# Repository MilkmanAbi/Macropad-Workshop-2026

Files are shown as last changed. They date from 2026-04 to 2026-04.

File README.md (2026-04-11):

# SPIC Macropad Workshop 2026

<div align="center">

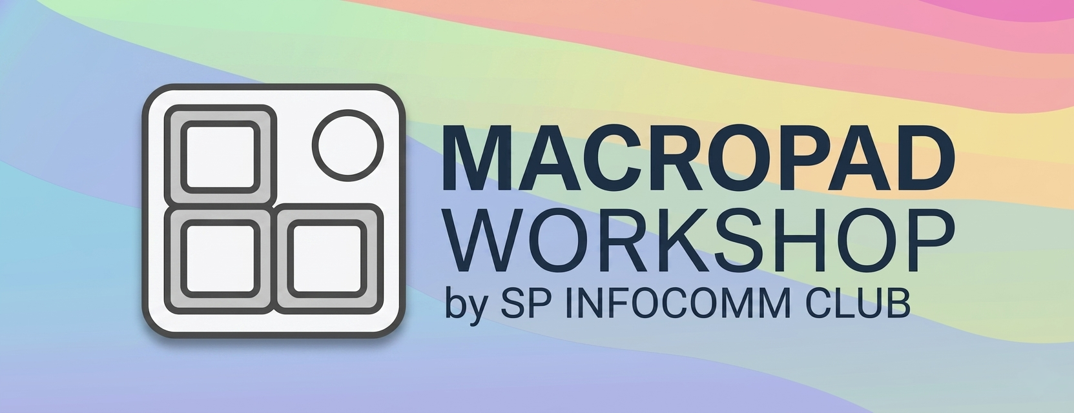
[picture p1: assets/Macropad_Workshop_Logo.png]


</div>

---

## “Yay! You made a custom keyboard… 😄”

“…Eh. A tiny one.”

**A MACROPAD!!! 😆✨**

SPIC Macropad Workshop 2026 💖

---

## What is this???

A macropad is a small programmable keyboard.

This one has **3 buttons**.

That sounds too small to matter…

…but it absolutely does.

You can turn it into:
- a productivity boost 😄  
- a media controller  
- a coding shortcut machine  
- or something completely unnecessary (but satisfying) 😆✨  

Basically: small device, big personality.

(￣ー￣)

---

## Why does this exist?

Because full keyboard firmware systems feel like too much pain for something this small.

So we don’t do that.

Instead:

- Plug it in  
- Edit a simple file  
- It works instantly  

No compiling. No waiting. No “why dis broken again” moments.

Just simple control. 💖

---

## What you’ll use

- CircuitPython  
- A RP2040 board  
- 3 buttons  
- 1 RGB LED that reflects your mode... or mood 😄✨  

That’s it.

And somehow, that’s enough.

(｡•̀ᴗ-)✧

---

## What it does

Each button can do different things depending on the mode.

For example:
- Copy / Paste / Cut  
- Volume control / media playback  
- Save / Undo / Redo  
- Zoom / Teams / Discord shortcuts  
- Or your own custom chaos 😆  

Same buttons. Different behaviour. New personality.

---

## Modes

The LED tells you what mode you are in.

And each mode changes what the 3 buttons do.

You’ll find:
- Clipboard mode 😄  
- Media mode  
- Coding mode 💖  
- Communication mode (Zoom / Teams / Discord)  
- Custom mode ✨  
- A “why did I do this” mode 😆  

(you’ll understand when you see it)

---

## Switching modes

Press Button 1 + Button 2 together.

The LED changes.

That’s it.

You are now in a different mode.

(￣▽￣)

---

## Custom mode

There is a simple config file where you can define your own setup.

You choose:
- what each button does  
- what color the LED shows  
- whether it behaves normally or becomes slightly unhinged (you'll see...) 😆✨  

No complicated setup. Just edit and save.

---

## Philosophy

This is not about building a complex system.

It’s about making something small feel useful and fun.

Fast to change. Easy to understand. Immediate feedback.

If it feels complicated, it is wrong. 💖

---

## SPIC Macropad Workshop 2026

You came in thinking:

“it’s just 3 buttons…”

You leave thinking:

“Small... But big in personality... Eh.” 😄✨

---

Credits to Organisers of 2025 Macropad Workshop and Jerick Seng

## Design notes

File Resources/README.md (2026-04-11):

# Macropad Workshop
These are the files to be used in conjunction with the macropad workshop. all software files can be found under /firmware and all hardware design files can be found under hardware

This is a 3 key macropad powered either by *QMK+VIAL* or *CIRCUITPYTHON*.

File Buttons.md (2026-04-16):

## Button Layout

</div>

**Layer 0 — Clipboard** `LED: Cyan`
| BTN1 | BTN2 | BTN3 |
|---|---|---|
| Copy | Paste | Cut |

**Layer 1 — Media** `LED: Purple`
| BTN1 | BTN2 | BTN3 |
|---|---|---|
| Vol Up | Vol Down | Play/Pause |

**Layer 2 — Communication** `LED: Orange`
| BTN1 | BTN2 | BTN3 |
|---|---|---|
| Mic Toggle | Speaker Mute | Cam Toggle |

> Long press BTN1+BTN2 on this layer to cycle platform: **Teams → Zoom → Discord** (LED blinks 2/3/4 times to confirm)

**Layer 3 — Coding** `LED: Red`
| BTN1 | BTN2 | BTN3 |
|---|---|---|
| Save | Undo | Redo |

**Layer 4 — Roll** `LED: Rainbow`
| BTN1 | BTN2 | BTN3 |
|---|---|---|
| Open Browser | Secret | Secret |

**Layer 5 — Custom** `LED: Mint (default)`
> Configured via `custom.conf` — no Python needed. See file for options.

**Layer switching:** Short press BTN1+BTN2 together → next layer

---

<div align="center">

## 🎮 Secret Game Mode

</div>

Press **all three buttons at once** to trigger a hidden Simon Says memory game.

- **BTN1 = Red · BTN2 = Green · BTN3 = Blue**
- Watch the LED flash a sequence, then repeat it in order
- 3 rounds of increasing length
- Pass all 3 rounds to claim your prize 👀

---

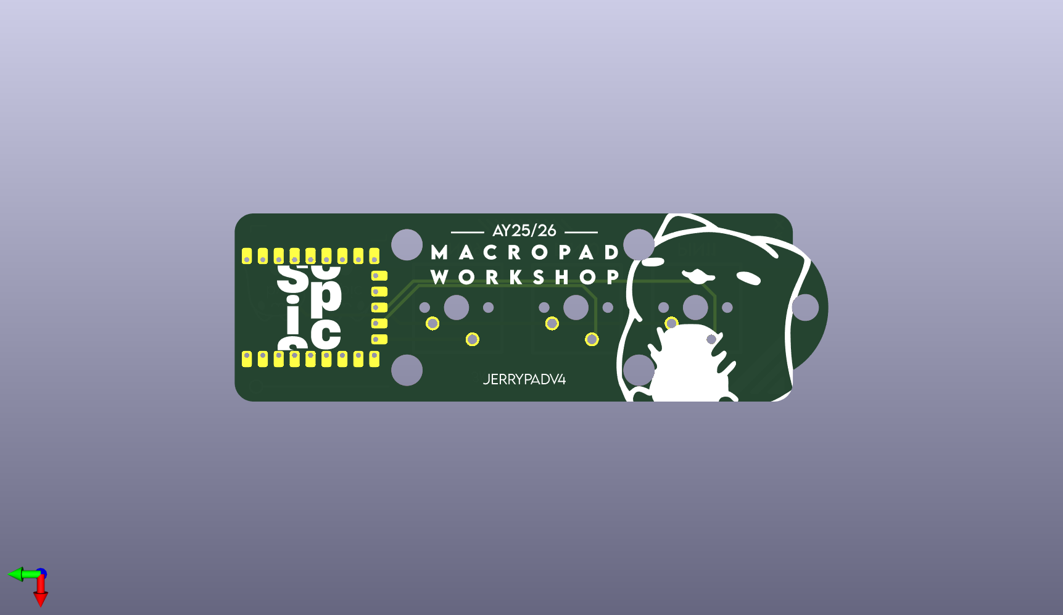
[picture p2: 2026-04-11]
Resources/Hardware-Design/V2/pcb/bottom.png

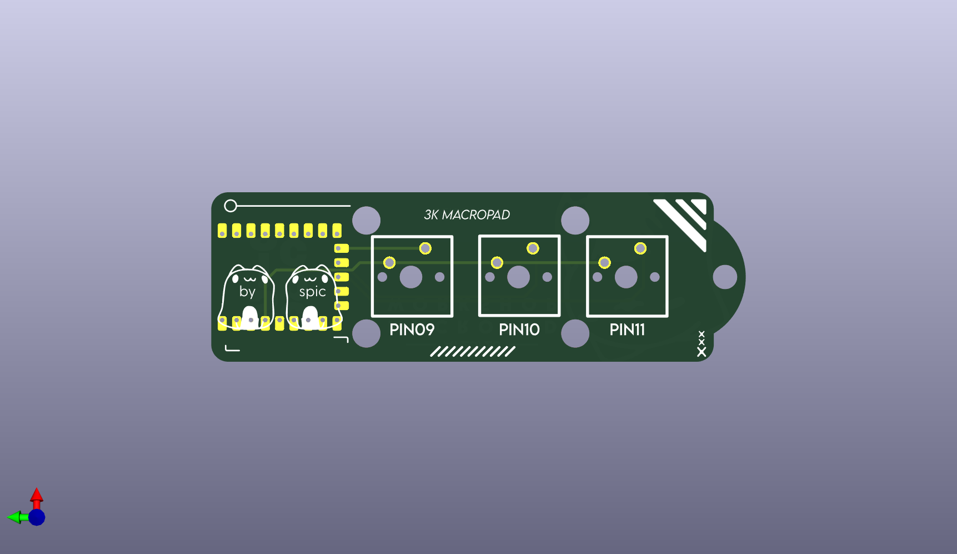
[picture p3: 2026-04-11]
Resources/Hardware-Design/V2/pcb/top.png

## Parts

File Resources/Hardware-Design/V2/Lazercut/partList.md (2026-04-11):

# Number to cut
Top.dxf x 1
Top mid.dxf x 1
Bottom Mid.dxf x 2
Base.dxf x1

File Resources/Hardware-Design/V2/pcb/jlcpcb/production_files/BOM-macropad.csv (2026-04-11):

Comment | Designator | Footprint | LCSC | Quantity
SW_SPST | SW1 | SW_Cherry_MX_1.00u_PCB |  | 1
SW_SPST | SW2 | SW_Cherry_MX_1.00u_PCB |  | 1
SW_SPST | SW3 | SW_Cherry_MX_1.00u_PCB |  | 1
RP2040-Zero | RZ1 | RP2040-Zero |  | 1

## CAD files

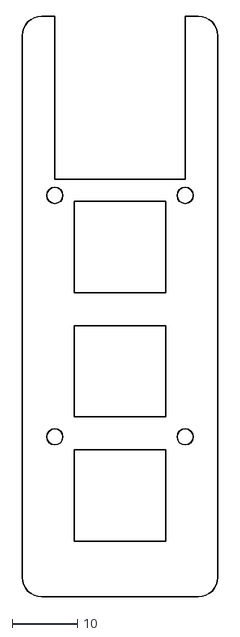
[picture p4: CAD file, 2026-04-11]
Resources/Hardware-Design/V2/Lazercut/Top.dxf
30.0 x 89.0

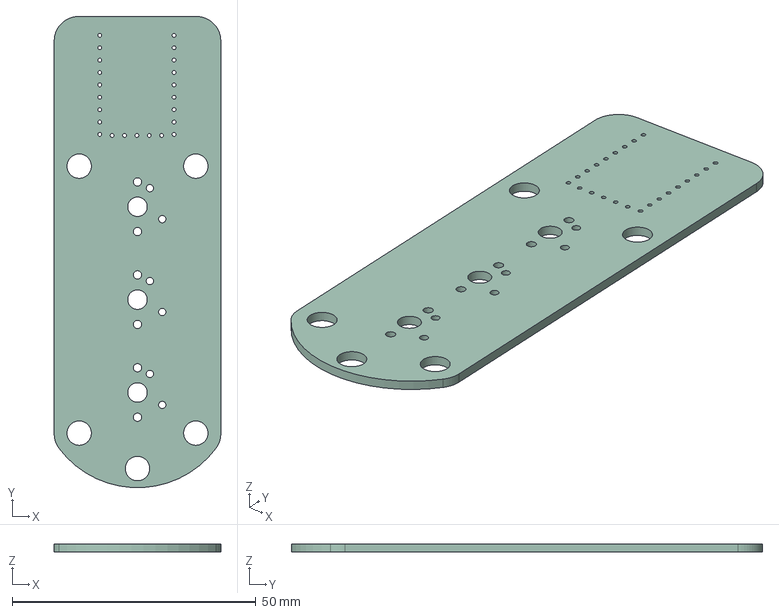
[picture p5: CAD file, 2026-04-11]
Resources/Hardware-Design/V2/pcb/macropad.step
34.2 x 96.6 x 1.60 mm

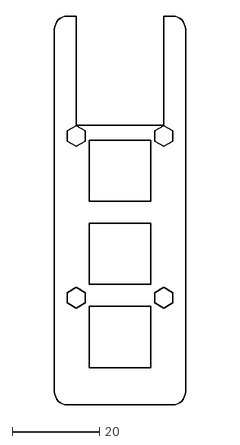
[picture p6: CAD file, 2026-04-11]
Resources/Hardware-Design/V2/Lazercut/Top mid.dxf
30.0 x 89.0

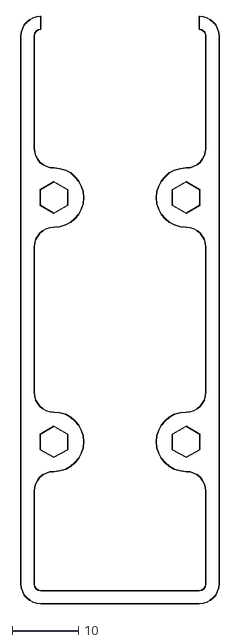
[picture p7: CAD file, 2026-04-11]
Resources/Hardware-Design/V2/Lazercut/Bottom Mid.dxf
30.0 x 89.0

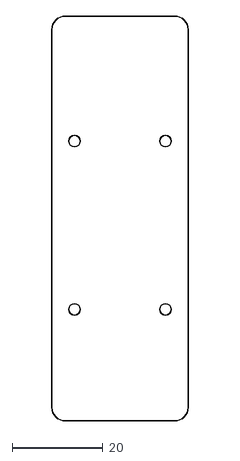
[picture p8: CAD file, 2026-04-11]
Resources/Hardware-Design/V2/Lazercut/Base.dxf
30.0 x 89.0

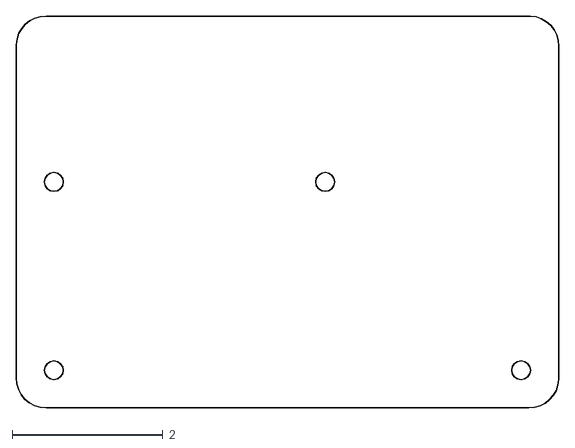
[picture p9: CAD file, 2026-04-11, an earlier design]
Resources/Hardware-Design/V1/lazercut/bottom_plate.dxf
7.20 x 5.20

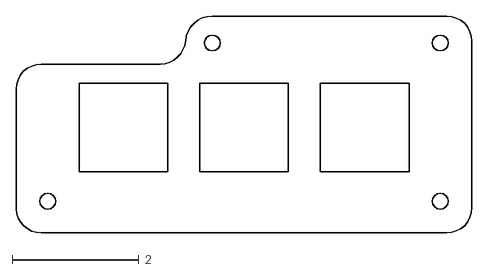
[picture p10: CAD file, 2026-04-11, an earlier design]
Resources/Hardware-Design/V1/lazercut/top_plate.dxf
7.20 x 3.43

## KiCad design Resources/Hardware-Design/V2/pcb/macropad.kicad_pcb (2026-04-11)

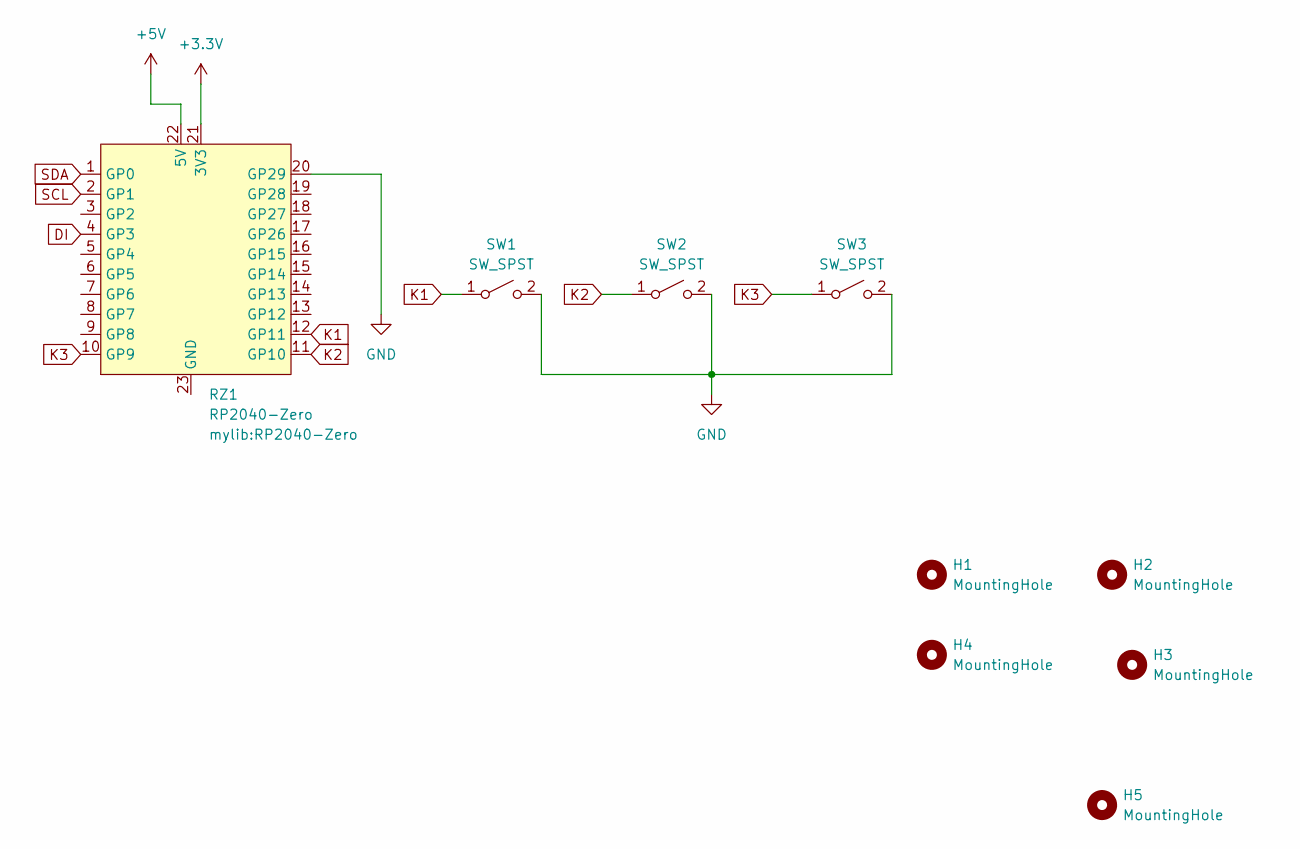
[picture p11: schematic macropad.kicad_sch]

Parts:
H1, H2, H3, H4, H5: MountingHole; MountingHole_5mm
RZ1: RP2040-Zero
SW1, SW2, SW3: SW_SPST; SW_Cherry_MX_1.00u_PCB

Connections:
+3.3V: RZ1.21 (3V3)
+5V: RZ1.22 (5V)
DI: RZ1.4 (GP3)
GND: RZ1.20 (GP29), SW1.2 (B), SW2.2 (B), SW3.2 (B)
K1: RZ1.12 (GP11), SW1.1 (A)
K2: RZ1.11 (GP10), SW2.1 (A)
K3: RZ1.10 (GP9), SW3.1 (A)
SCL: RZ1.2 (GP1)
SDA: RZ1.1 (GP0)

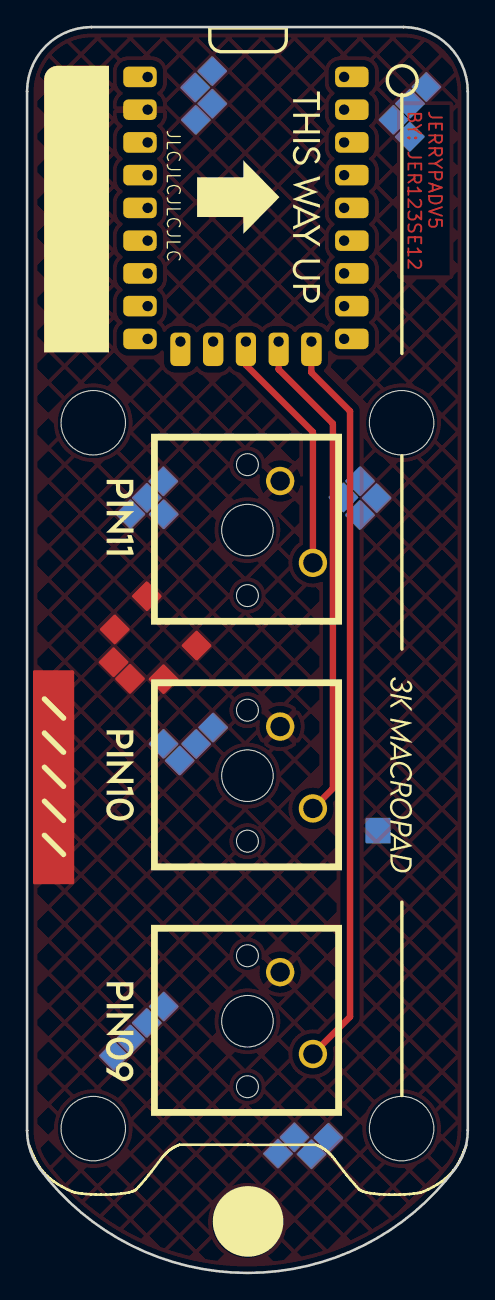
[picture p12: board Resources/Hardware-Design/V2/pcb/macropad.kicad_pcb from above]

Board: 2 copper layers, 34.2 x 96.7 mm, 9 parts (0 on the bottom side), 4 nets.

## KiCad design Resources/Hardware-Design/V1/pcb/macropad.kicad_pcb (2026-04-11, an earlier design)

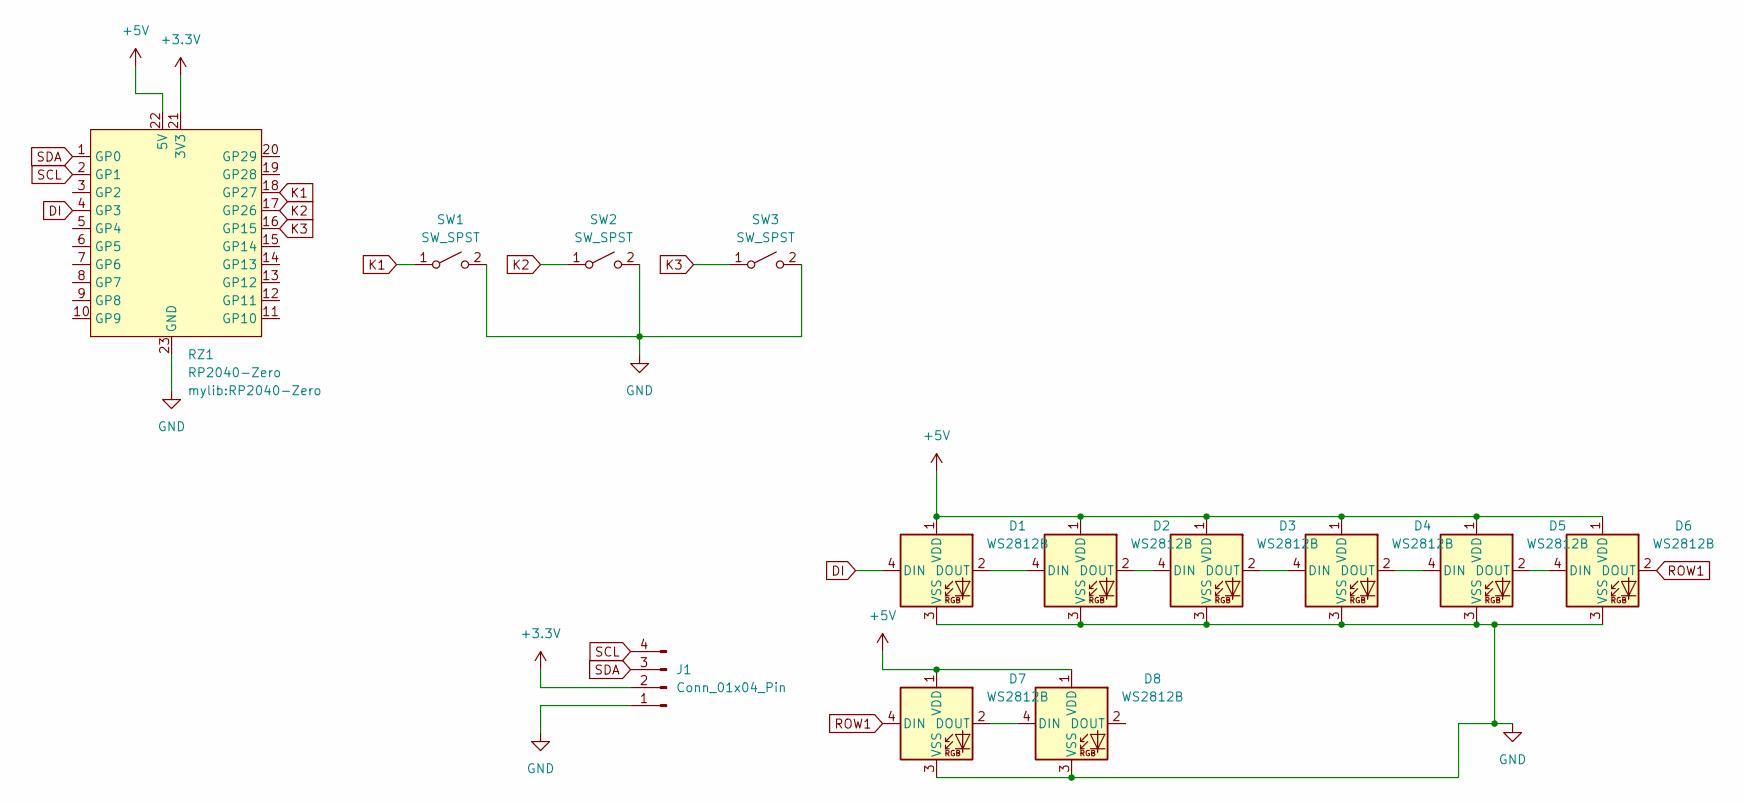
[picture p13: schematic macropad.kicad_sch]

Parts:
D1, D2, D3, D4, D5, D6, D7, D8: WS2812B; new led
J1: Conn_01x04_Pin; FanPinHeader_1x04_P2.54mm_Vertical
RZ1: RP2040-Zero
SW1, SW2, SW3: SW_SPST; SW_Cherry_MX_1.00u_PCB

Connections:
+3.3V: J1.2, RZ1.21 (3V3)
+5V: D1.1 (VDD), D2.1 (VDD), D3.1 (VDD), D4.1 (VDD), D5.1 (VDD), D6.1 (VDD), D7.1 (VDD), D8.1 (VDD), RZ1.22 (5V)
DI: D1.4 (DIN), RZ1.4 (GP3)
GND: D1.3 (VSS), D2.3 (VSS), D3.3 (VSS), D4.3 (VSS), D5.3 (VSS), D6.3 (VSS), D7.3 (VSS), D8.3 (VSS), J1.1, RZ1.23 (GND), SW1.2 (B), SW2.2 (B), SW3.2 (B)
K1: RZ1.18 (GP27), SW1.1 (A)
K2: RZ1.17 (GP26), SW2.1 (A)
K3: RZ1.16 (GP15), SW3.1 (A)
unnamed: D1.2 (DOUT), D2.4 (DIN)
unnamed: D2.2 (DOUT), D3.4 (DIN)
unnamed: D3.2 (DOUT), D4.4 (DIN)
unnamed: D4.2 (DOUT), D5.4 (DIN)
unnamed: D5.2 (DOUT), D6.4 (DIN)
unnamed: D7.2 (DOUT), D8.4 (DIN)
ROW1: D6.2 (DOUT), D7.4 (DIN)
SCL: J1.4, RZ1.2 (GP1)
SDA: J1.3, RZ1.1 (GP0)

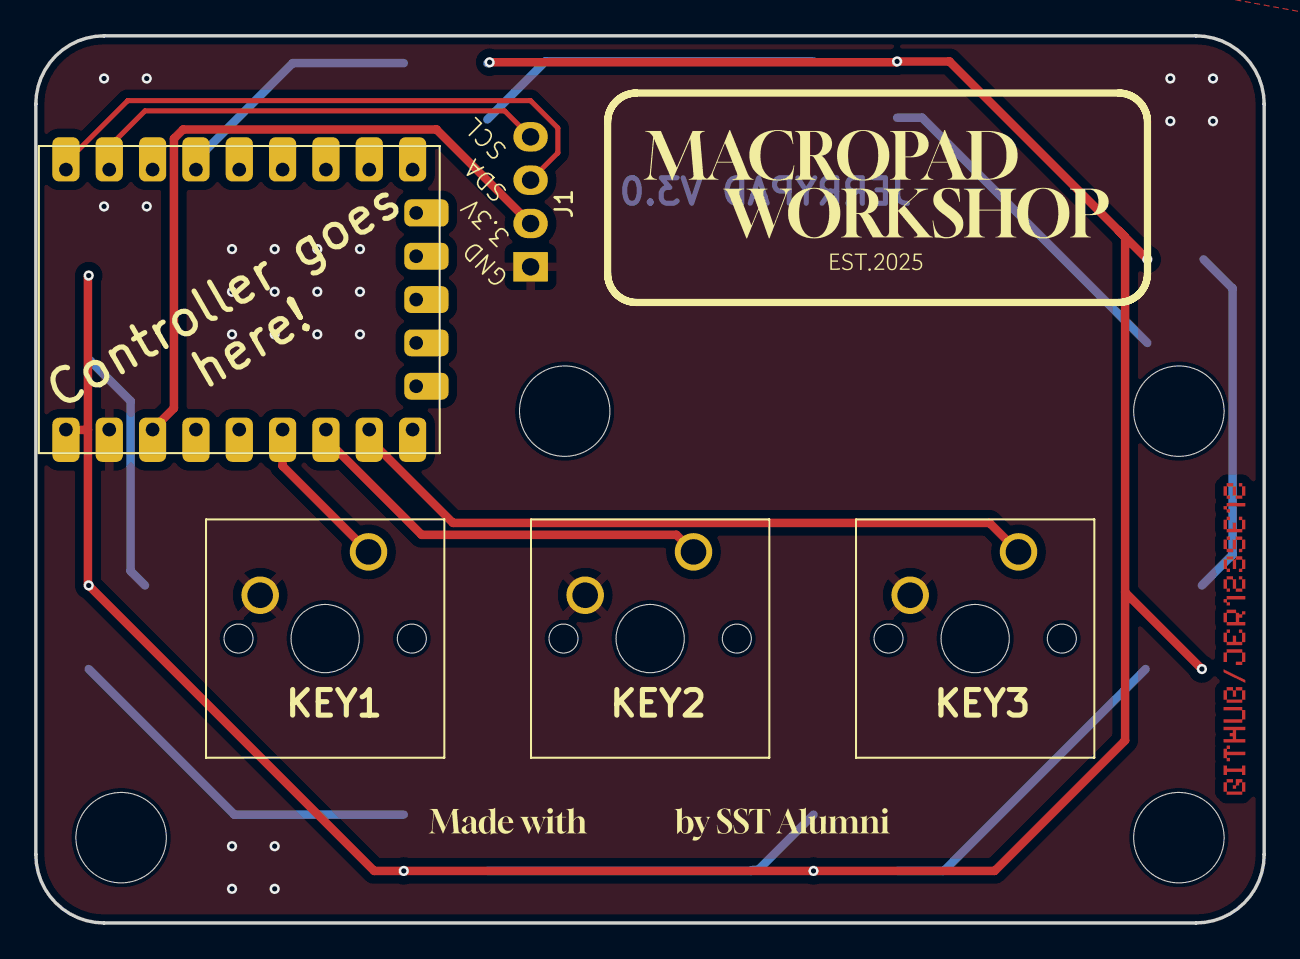
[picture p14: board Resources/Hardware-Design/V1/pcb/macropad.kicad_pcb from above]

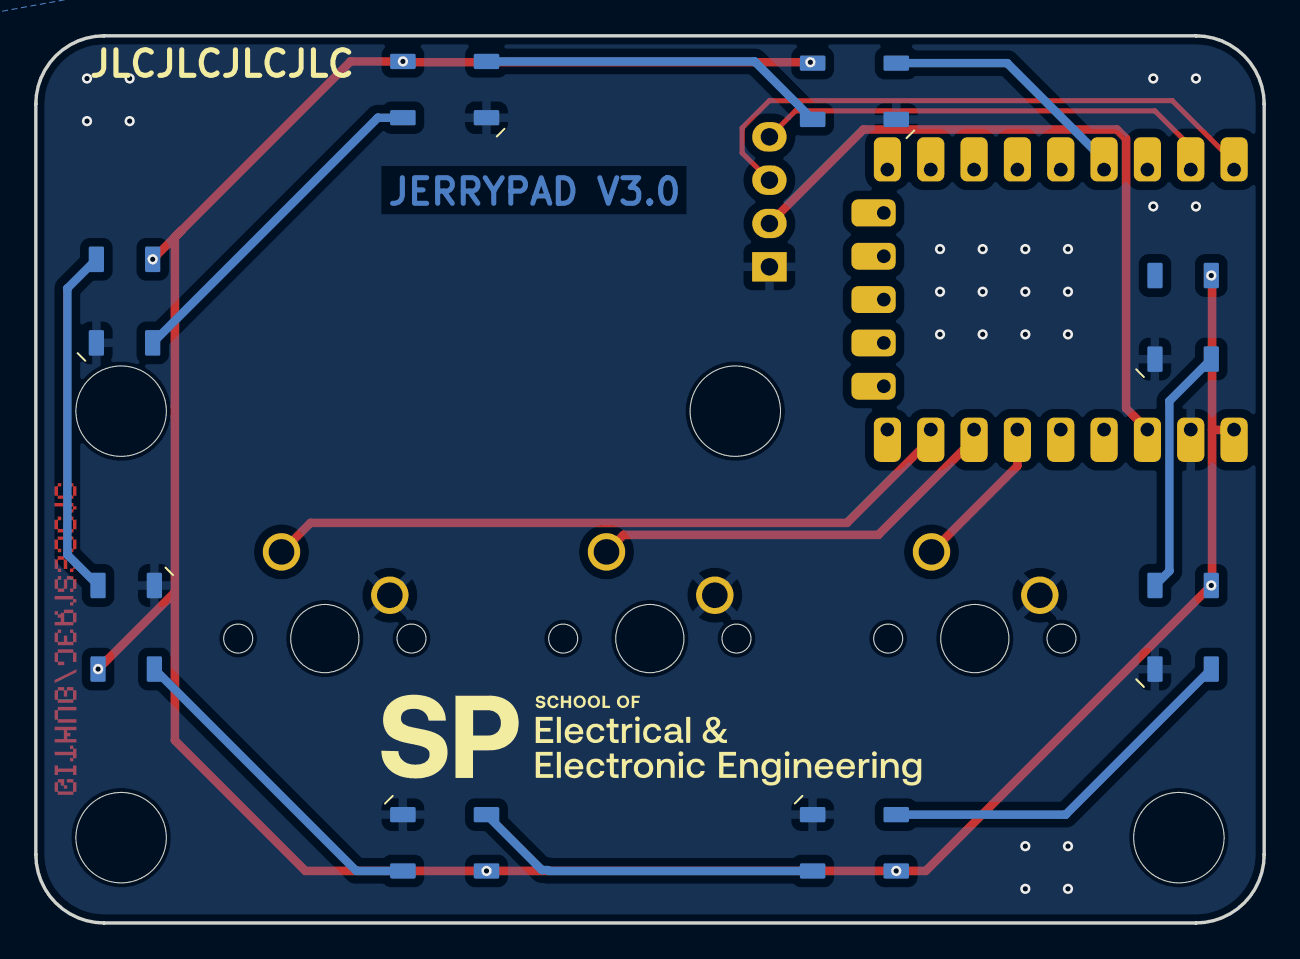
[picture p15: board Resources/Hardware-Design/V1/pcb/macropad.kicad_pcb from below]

Board: 2 copper layers, 72.0 x 52.0 mm, 13 parts (8 on the bottom side), 16 nets.

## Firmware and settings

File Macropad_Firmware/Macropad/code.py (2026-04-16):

"""
code.py — Macropad Workshop 2026
Main runtime: GPIO, mode switching, LED, execution routing.
Edit freely. No compiling. No tools. Just save and run.

Button 1 = GP9 | Button 2 = GP10 | Button 3 = GP11 | LED = GP16
"""

import board
import digitalio
import neopixel
import time
from keymaps import LAYERS, execute_action, build_custom_layer

# ── GP29 virtual GND — pull low FIRST before anything else ───────────────────
# The PCB routes switch GND through GP29 instead of actual GND.
# Must be driven low immediately or buttons are floating and won't work.
_gnd = digitalio.DigitalInOut(board.GP29)
_gnd.direction = digitalio.Direction.OUTPUT
_gnd.value = False

# ── Hardware ──────────────────────────────────────────────────────────────────

BTN_PINS = [board.GP9, board.GP10, board.GP11]
LED_PIN  = board.GP16

buttons = []
for pin in BTN_PINS:
    b = digitalio.DigitalInOut(pin)
    b.direction = digitalio.Direction.INPUT
    b.pull = digitalio.Pull.UP      # Pull-up: LOW = pressed, HIGH = not pressed
    buttons.append(b)

# pixel_order=neopixel.GRB is the WS2812B standard — stated explicitly for clarity
led = neopixel.NeoPixel(LED_PIN, 1, brightness=0.3, auto_write=True,
                        pixel_order=neopixel.GRB)

# ── Load custom.conf ──────────────────────────────────────────────────────────

def load_custom_conf():
    conf = {}
    try:
        with open("custom.conf", "r") as f:
            for line in f:
                line = line.strip()
                if not line or line.startswith("#"):
                    continue
                if "=" in line:
                    key, _, val = line.partition("=")
                    conf[key.strip().upper()] = val.strip()
    except OSError:
        pass
    return conf

LAYERS.append(build_custom_layer(load_custom_conf()))

# ── LED helpers ───────────────────────────────────────────────────────────────

RAINBOW_COLORS = [
    (255, 0,   0),
    (255, 127, 0),
    (255, 255, 0),
    (0,   255, 0),
    (0,   0,   255),
    (75,  0,   130),
    (148, 0,   211),
]
_rainbow_idx  = 0
_last_rainbow = 0.0

def set_led(color):
    if color != "RAINBOW":
        led[0] = color

def update_rainbow():
    global _rainbow_idx, _last_rainbow
    now = time.monotonic()
    if now - _last_rainbow >= 0.15:
        led[0] = RAINBOW_COLORS[_rainbow_idx % len(RAINBOW_COLORS)]
        _rainbow_idx  += 1
        _last_rainbow  = now

def blink_led(color, count, on_s=0.12, off_s=0.10):
    for _ in range(count):
        led[0] = color
        time.sleep(on_s)
        led[0] = (0, 0, 0)
        time.sleep(off_s)

# ── Comms sub-platform state ──────────────────────────────────────────────────
# Platforms cycle with LONG press of B1+B2 while on the comms layer.
# 0 = Teams (2 blinks), 1 = Zoom (3 blinks), 2 = Discord (4 blinks)

# MilkmanAbi: FUCK. I genuinely dunno if there's a bug here or nah, hn. Idk, just test later OwO

COMMS_LAYER_NAME = "Communication"
COMMS_PLATFORMS  = [2, 3, 4]
_comms_platform_idx = 0

def current_comms_blinks():
    return COMMS_PLATFORMS[_comms_platform_idx % len(COMMS_PLATFORMS)]

def cycle_comms_platform():
    global _comms_platform_idx
    _comms_platform_idx = (_comms_platform_idx + 1) % len(COMMS_PLATFORMS)
    blinks = current_comms_blinks()
    layer  = LAYERS[current_mode]
    print("[Comms] Platform blinks:", blinks)
    time.sleep(0.3)
    blink_led(layer["color"], count=blinks)

# ── Mode state ────────────────────────────────────────────────────────────────

current_mode = 0

def activate_mode(idx):
    global current_mode
    current_mode = idx % len(LAYERS)
    layer = LAYERS[current_mode]
    color = layer.get("color", (255, 255, 255))
    set_led(color)
    print("[Mode] ->", layer["name"])
    if layer["name"] == COMMS_LAYER_NAME:
        time.sleep(0.3)
        blink_led(layer["color"], count=current_comms_blinks())

activate_mode(0)

# ── Timing constants ──────────────────────────────────────────────────────────

DEBOUNCE_S   = 0.03   # 30 ms minimum to count as a real press
SHORT_HOLD_S = 0.05   # B1+B2 minimum to count as intentional (not accidental)
LONG_HOLD_S  = 0.80   # B1+B2 held >= 800ms = long press

# ── Button state ──────────────────────────────────────────────────────────────

prev_raw   = [False, False, False]
pressed_at = [0.0, 0.0, 0.0]

def read_buttons():
    return [not b.value for b in buttons]

# ── Memory Game ───────────────────────────────────────────────────────────────
# Triggered by pressing ALL THREE buttons at once.
# 4 rounds of increasing sequence length. Match the colours to win.
# B1 = Red, B2 = Blue, B3 = Green
# Win = rickroll. Always.

GAME_COLORS = [
    (200, 0,   0  ),   # B1 — GP9  — Red
    (0,   200, 0  ),   # B2 — GP10 — Green
    (0,   0,   200),   # B3 — GP11 — Blue
]

# ── Speed control ─────────────────────────────────────────────────────────────
# GAME_SPEED: multiplier on all timings. Higher = slower.
#   0.5 = fast (punishing)
#   1.0 = default
#   1.8 = slow and comfy (good for carnival — want people to win)
# SPEED_RAMP: how much GAME_SPEED shrinks each round (0 = no ramp).
#   0.0 = same speed all 4 rounds
#   0.1 = gets slightly faster each round (adds a little pressure by round 4)
GAME_SPEED = 1.8
SPEED_RAMP = 0.1

# Pre-set sequences per round — keeps difficulty fair and showable
GAME_ROUNDS = [
    [1, 2, 0, 2],           # Round 1 — 4 steps
    [2, 0, 1, 2, 2, 0],     # Round 2 — 6 steps
    [0, 1, 2, 0, 1, 2, 1],  # Round 3 — 7 steps
]

def _game_flash(btn_idx, spd, duration=0.35):
    led[0] = GAME_COLORS[btn_idx]
    time.sleep(duration * spd)
    led[0] = (0, 0, 0)
    time.sleep(0.15 * spd)

def _game_show_sequence(seq, spd):
    """Flash the sequence for the player to watch."""
    time.sleep(0.4 * spd)
    for idx in seq:
        _game_flash(idx, spd)
    time.sleep(0.2 * spd)

def _game_wait_input(expected_seq):
    """Wait for player to press buttons in order. Returns True if correct."""
    # Drain any buttons still held from the sequence show or previous press
    while any(read_buttons()):
        time.sleep(0.005)
    time.sleep(0.05)  # extra settle time

    for expected in expected_seq:
        # Wait for a single button press
        pressed = None
        while pressed is None:
            raw = read_buttons()
            for i in range(3):
                if raw[i]:
                    pressed = i
                    break
            time.sleep(0.005)

        # Wait for release
        while read_buttons()[pressed]:
            time.sleep(0.005)

        if pressed != expected:
            # Wrong! Flash red fast 3x
            for _ in range(3):
                led[0] = (255, 0, 0)
                time.sleep(0.08)
                led[0] = (0, 0, 0)
                time.sleep(0.08)
            print("[Game] WRONG! Expected B" + str(expected+1) + " got B" + str(pressed+1))
            return False

        # Correct — brief flash of the right colour as feedback
        led[0] = GAME_COLORS[pressed]
        time.sleep(0.12)
        led[0] = (0, 0, 0)
        time.sleep(0.08)

    return True

def _game_round_pass():
    """White flash = round cleared."""
    for _ in range(2):
        led[0] = (200, 200, 200)
        time.sleep(0.18)
        led[0] = (0, 0, 0)
        time.sleep(0.12)

def _game_win():
    """Rainbow flash then rickroll."""
    print("[Game] YOU WIN! Initiating surprise...")
    for color in [(255,0,0),(255,127,0),(0,255,0),(0,0,255),(148,0,211)]:
        led[0] = color
        time.sleep(0.1)
    led[0] = (0, 0, 0)
    time.sleep(0.2)
    from keymaps import execute_action as _ea
    _ea("OPENWEBSITE = https://www.youtube.com/watch?v=klfT41uZniI")

def run_memory_game():
    print("[Game] Entering memory game mode!")
    # Startup animation — cycle R G B
    for c in GAME_COLORS:
        led[0] = c
        time.sleep(0.2)
    led[0] = (0, 0, 0)
    time.sleep(0.5)

    spd = GAME_SPEED  # local copy so GAME_SPEED constant stays untouched

    for round_num, seq in enumerate(GAME_ROUNDS):
        print("[Game] Round", round_num + 1, "spd:", spd, "seq:", seq)

        # Show the sequence at current speed
        _game_show_sequence(seq, spd)

        # Get input (no time pressure on input — just sequence show speed ramps)
        if not _game_wait_input(seq):
            print("[Game] Game over. Back to normal mode.")
            time.sleep(0.5)
            activate_mode(current_mode)
            return

        # Round cleared
        _game_round_pass()
        print("[Game] Round", round_num + 1, "cleared!")
        time.sleep(0.4)

        # Ramp up speed for next round (lower spd = faster flashes)
        spd = max(0.4, spd - SPEED_RAMP)

    # All 4 rounds done — they earned the rickroll
    _game_win()
    time.sleep(1.0)
    activate_mode(current_mode)

# ── Main loop ─────────────────────────────────────────────────────────────────

print("Ready. B1+B2 short=next layer, long=next comms platform")

while True:
    now = time.monotonic()
    layer = LAYERS[current_mode]

    if layer.get("color") == "RAINBOW":
        update_rainbow()

    raw = read_buttons()

    # ── B1+B2+B3 chord — secret game mode trigger ────────────────────────────
    if raw[0] and raw[1] and raw[2]:
        # Wait for all released
        while any(read_buttons()):
            time.sleep(0.005)
        prev_raw   = [False, False, False]
        pressed_at = [time.monotonic()] * 3
        run_memory_game()
        continue

    # ── B1+B2 chord detection ────────────────────────────────────────────────
    # Wait for the chord to fully release, then decide short vs long.

    if raw[0] and raw[1] and not raw[2]:
        chord_start = time.monotonic()

        # Spin until both buttons are released (or B3 pressed = cancel)
        while True:
            still = read_buttons()
            if not still[0] or not still[1] or still[2]:
                break
            time.sleep(0.005)

        held = time.monotonic() - chord_start

        if held >= LONG_HOLD_S:
            if layer["name"] == COMMS_LAYER_NAME:
                cycle_comms_platform()
            else:
                activate_mode(current_mode + 1)
        elif held >= SHORT_HOLD_S:
            activate_mode(current_mode + 1)
        # else: too short, ignore

        # Reset state — prevents ghost-firing B1/B2 actions on release
        prev_raw   = [False, False, False]
        pressed_at = [time.monotonic(), time.monotonic(), time.monotonic()]
        time.sleep(0.05)
        continue

    # ── Individual buttons ───────────────────────────────────────────────────
    for i in range(3):
        if raw[i] and not prev_raw[i]:
            pressed_at[i] = now

        if not raw[i] and prev_raw[i]:
            held = now - pressed_at[i]
            if held >= DEBOUNCE_S:
                action = layer.get("btn" + str(i + 1))
                if action:
                    if layer["name"] == COMMS_LAYER_NAME:
                        effective_layer = dict(layer)
                        effective_layer["platform_blinks"] = current_comms_blinks()
                    else:
                        effective_layer = layer
                    print("[Press] B" + str(i + 1) + " ->", action)
                    execute_action(action, effective_layer)

        prev_raw[i] = raw[i]

    time.sleep(0.005)

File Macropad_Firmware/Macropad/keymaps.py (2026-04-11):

"""
keymaps.py — Macropad Workshop 2026
All layers, keybindings, macros, and the action executor.
Hack this file. Add actions, change bindings. No compiling needed.
"""

import usb_hid
import time
from adafruit_hid.keyboard import Keyboard
from adafruit_hid.keyboard_layout_us import KeyboardLayoutUS
from adafruit_hid.keycode import Keycode
from adafruit_hid.consumer_control import ConsumerControl
from adafruit_hid.consumer_control_code import ConsumerControlCode

# ── HID devices ───────────────────────────────────────────────────────────────

kbd    = Keyboard(usb_hid.devices)
layout = KeyboardLayoutUS(kbd)
cc     = ConsumerControl(usb_hid.devices)

# ── Layer definitions ─────────────────────────────────────────────────────────
# btn1/btn2/btn3 = action string (see execute_action for full list)
# color          = (R, G, B) tuple or "RAINBOW"
# Custom layer is appended at runtime by code.py after reading custom.conf

LAYERS = [
    # 1. Clipboard — Cyan
    {
        "name":  "Clipboard",
        "color": (0, 200, 200),
        "btn1":  "COPY",
        "btn2":  "PASTE",
        "btn3":  "CUT",
    },
    # 2. Media — Purple
    {
        "name":  "Media",
        "color": (120, 0, 200),
        "btn1":  "VOL_UP",
        "btn2":  "VOL_DOWN",
        "btn3":  "PLAY_PAUSE",
    },
    # 3. Communication — Orange
    # platform_blinks is set here as the DEFAULT only.
    # At runtime, code.py manages the live platform via _comms_platform_idx
    # and injects the correct blinks count before calling execute_action.
    # Long press B1+B2 cycles: Teams(2) -> Zoom(3) -> Discord(4) -> Teams
    {
        "name":            "Communication",
        "color":           (255, 80, 0),
        "platform_blinks": 2,
        "btn1":            "MIC_TOGGLE",
        "btn2":            "SPEAKER_MUTE",
        "btn3":            "CAM_TOGGLE",
    },
    # 4. Coding — Red
    {
        "name":  "Coding",
        "color": (200, 0, 0),
        "btn1":  "SAVE",
        "btn2":  "UNDO",
        "btn3":  "REDO",
    },
    # 5. Troll — Rainbow
    {
        "name":  "Troll",
        "color": "RAINBOW",
        "btn1":  "OPEN_BROWSER",
        "btn2":  "RICKROLL",
        "btn3":  "NYAN_CAT",
    },
    # 6. Custom — loaded from custom.conf by code.py
]

# ── Platform shortcuts ────────────────────────────────────────────────────────
# Keyed by platform_blinks value (2=Teams, 3=Zoom, 4=Discord)
# None = no shortcut exists for that action on that platform

COMMS_SHORTCUTS = {
    # Microsoft Teams
    2: {
        "MIC_TOGGLE":   ([Keycode.CONTROL, Keycode.SHIFT], Keycode.M),
        "SPEAKER_MUTE": None,
        "CAM_TOGGLE":   ([Keycode.CONTROL, Keycode.SHIFT], Keycode.O),
    },
    # Zoom
    3: {
        "MIC_TOGGLE":   ([Keycode.ALT], Keycode.A),
        "SPEAKER_MUTE": None,
        "CAM_TOGGLE":   ([Keycode.ALT], Keycode.V),
    },
    # Discord
    4: {
        "MIC_TOGGLE":   ([Keycode.CONTROL, Keycode.SHIFT], Keycode.M),
        "SPEAKER_MUTE": ([Keycode.CONTROL, Keycode.SHIFT], Keycode.D),
        "CAM_TOGGLE":   ([Keycode.CONTROL, Keycode.SHIFT], Keycode.V),
    },
}

# ── HID helpers ───────────────────────────────────────────────────────────────

def _tap(*keycodes):
    kbd.press(*keycodes)
    time.sleep(0.05)
    kbd.release_all()
    time.sleep(0.05)

def _type(text):
    layout.write(text)
    time.sleep(0.04)

def _open_run_dialog():
    _tap(Keycode.WINDOWS, Keycode.R)
    time.sleep(0.6)

def _open_url(url):
    """Rubber-ducky: Win+R -> type URL -> Enter. Works on any Windows machine."""
    _open_run_dialog()
    _type(url)
    time.sleep(0.1)
    _tap(Keycode.ENTER)

# ── Action executor ───────────────────────────────────────────────────────────
# Add new actions here and they work everywhere: layers + custom.conf.
#
# Normalisation rules (handles spaces from custom.conf partition parsing):
#   "COPY"                          -> cmd="COPY",        val=""
#   "OPENWEBSITE = https://..."     -> cmd="OPENWEBSITE", val="https://..."
#   "TYPE = hello world"            -> cmd="TYPE",        val="hello world"  (case preserved)
#   "SHORTCUT = CTRL+SHIFT+T"       -> cmd="SHORTCUT",    val="CTRL+SHIFT+T"

def execute_action(action, layer=None):
    action = action.strip()

    if "=" in action:
        cmd = action.split("=", 1)[0].strip().upper()
        val = action.split("=", 1)[1].strip()   # preserve case for TYPE/URLs
    else:
        cmd = action.strip().upper()
        val = ""

    # ── Clipboard ─────────────────────────────────────────────────────────────
    if cmd == "COPY":
        _tap(Keycode.CONTROL, Keycode.C)

    elif cmd == "PASTE":
        _tap(Keycode.CONTROL, Keycode.V)

    elif cmd == "CUT":
        _tap(Keycode.CONTROL, Keycode.X)

    elif cmd == "SELECT_ALL":
        _tap(Keycode.CONTROL, Keycode.A)

    # ── Editing ───────────────────────────────────────────────────────────────
    elif cmd == "SAVE":
        _tap(Keycode.CONTROL, Keycode.S)

    elif cmd == "UNDO":
        _tap(Keycode.CONTROL, Keycode.Z)

    elif cmd == "REDO":
        _tap(Keycode.CONTROL, Keycode.Y)

    elif cmd == "FIND":
        _tap(Keycode.CONTROL, Keycode.F)

    elif cmd == "NEW_TAB":
        _tap(Keycode.CONTROL, Keycode.T)

    elif cmd == "CLOSE_TAB":
        _tap(Keycode.CONTROL, Keycode.W)

    elif cmd == "SCREENSHOT":
        _tap(Keycode.WINDOWS, Keycode.SHIFT, Keycode.S)

    # ── Media ─────────────────────────────────────────────────────────────────
    elif cmd == "VOL_UP":
        cc.send(ConsumerControlCode.VOLUME_INCREMENT)

    elif cmd == "VOL_DOWN":
        cc.send(ConsumerControlCode.VOLUME_DECREMENT)

    elif cmd == "MUTE":
        cc.send(ConsumerControlCode.MUTE)

    elif cmd == "PLAY_PAUSE":
        cc.send(ConsumerControlCode.PLAY_PAUSE)

    elif cmd == "NEXT_TRACK":
        cc.send(ConsumerControlCode.SCAN_NEXT_TRACK)

    elif cmd == "PREV_TRACK":
        cc.send(ConsumerControlCode.SCAN_PREVIOUS_TRACK)

    # ── Comms (platform-aware) ────────────────────────────────────────────────
    elif cmd in ("MIC_TOGGLE", "SPEAKER_MUTE", "CAM_TOGGLE"):
        blinks = (layer or {}).get("platform_blinks", 2)
        combo  = COMMS_SHORTCUTS.get(blinks, {}).get(cmd)
        if combo:
            modifiers, key = combo
            kbd.press(*modifiers, key)
            time.sleep(0.05)
            kbd.release_all()

    # ── Browser / rubber ducky ────────────────────────────────────────────────
    elif cmd == "OPEN_BROWSER":
        _open_run_dialog()
        _type("https://")

    elif cmd == "RICKROLL":
        _open_url("https://www.youtube.com/watch?v=dQw4w9WgXcQ")

    elif cmd == "NYAN_CAT":
        _open_url("https://www.nyan.cat")

    elif cmd == "OPENWEBSITE":
        _open_url(val)              # val is the URL, case preserved

    elif cmd == "TYPE":
        _type(val)                  # val typed as-is, original case

    elif cmd == "SHORTCUT":
        _parse_shortcut(val.upper())
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

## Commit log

2026-04-11 Add Resources folder
    [BOM-macropad.csv, Base.dxf, Bottom Mid.dxf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]
2026-04-16 Rename Layer 4 and update button actions
